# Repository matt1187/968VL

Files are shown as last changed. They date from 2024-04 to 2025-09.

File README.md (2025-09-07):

# Project  MK-968VL 
An (old) project for 486 platform: Video card based S3 Vision 968 VLB with 4MB VRAM.
It is just a Replica of the SPEA Mercury P64V PCI, in which their PCI interface was replaced by a VLB interface.
It is my first project with KiCad, it may sometimes look not so good and weird.

[Full development history at Vogons](https://www.vogons.org/viewtopic.php?f=63&t=76602)

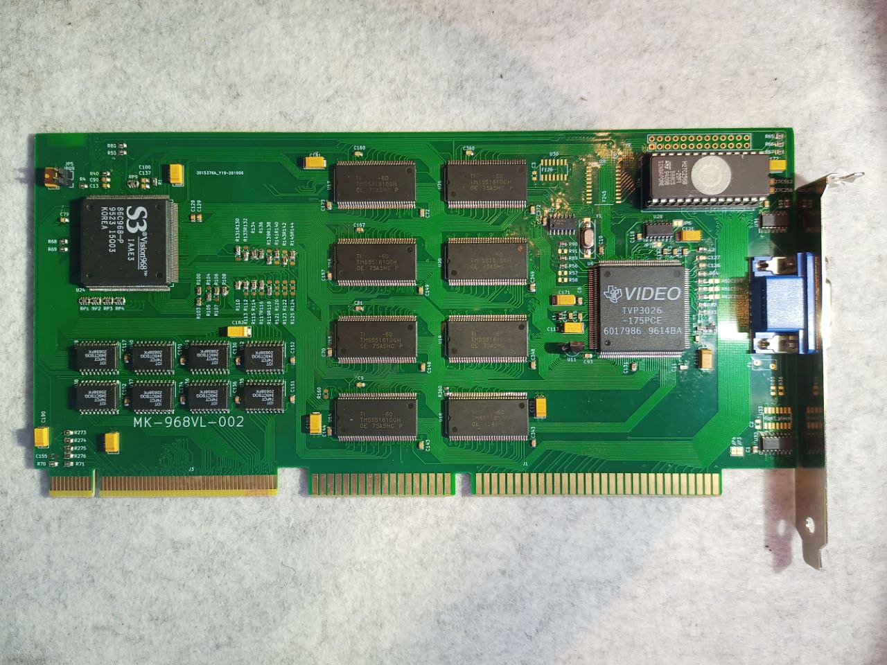
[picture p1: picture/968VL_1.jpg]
pictures


# Features
- S3 Vision968 video chipset, one of fastest Windows accelerator for the 486 VESA local bus platform
- 4 MB VRAM
- 175/220 MHz high quality RAMDAC
- Mostly rock solid 50 MHz bus clock with zero wait states
- Win 3.1 and Win 9x driver available

# Issues
- DDC interface is not working, fixing in future is not planned, sorry.
- heavy to find a S3 Vision968 (86C968) chip
- Card would work with a S3 Vision964 (86C964) too, but that would need modification of VGA-ROM (difference in registers) so that text/CGA/MDA modes work correctly
- Some (many) TVP3026 DAC has issuses with VESA 4bit Mode: Line Jitter  (my original SPEA Mercury P64V PCI has also line jitter) Side notice: I have two 968VL with good 4bit VESA mode

# Bill of Materials
- [**please read file "note_MK_968VL_002.txt"**](https://github.com/matt1187/968VL/blob/main/gerber/note_MK_968VL_002.txt)
- [config resistor picture](https://github.com/matt1187/968VL/blob/main/gerber/config_resistor.JPG)
- [bom csv file Rev 002 ](https://github.com/matt1187/968VL/blob/main/gerber/968.csv)
- [gerber files Rev 002 ](https://github.com/matt1187/968VL/blob/main/gerber/)
- [drawing of slot bracket rev 000-002 ](https://github.com/matt1187/968VL/blob/main/mechanical/bracket_968VL_01.pdf)

# Drivers & ROM
- [ROM dump](https://github.com/matt1187/968VL/blob/main/rom/968V_ROM.zip)
- [Windows 9x driver](https://github.com/matt1187/968VL/blob/main/driver/W95_S3_driver%200109B.ZIP)
- [Windows 3.1 driver](https://github.com/matt1187/968VL/blob/main/driver/WIN31_vision96815B4.ZIP)

# PCB Revision History
- 000 initial draft
- 001 major bug fixing (swapped inner layer, few wrong connections on ICs)
- 002 minor bug fixing (wrong footprint)
- 003 new revision moved VGA port (keystone 9200-1 instead special pc slot bracket) and corrected ISA slot position (12.7mm instead 13 mm  to VLB )

# License
The project is free for non-commercial reproduction. Do not sell it on Ebay or other platforms for profit. Do not make a closed source derivative. Share your experiences and ideas with the community.

This work is licensed under a [Creative Commons Attribution-NonCommercial-ShareAlike 4.0 International License][cc-by-nc-sa].

[][cc-by-nc-sa]

[cc-by-nc-sa]: http://creativecommons.org/licenses/by-nc-sa/4.0/
[cc-by-nc-sa-image]: https://licensebuttons.net/l/by-nc-sa/4.0/88x31.png

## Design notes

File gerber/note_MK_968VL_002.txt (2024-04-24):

Notice for make of   MK_968VL_002 card.

1.) most important: your risk  and  no right by full support.

Component-list:
U33			let U33 empty,  DDC Interface doesn't run right (and failed hardware cursor)
L3 & U11 	place L3 OR  U11, you must not place both at same time. I recommend  place  78L05 for better PLL stability

C155		optional, place it if 968VL is  restarting sometimes.
C103,C104,C105  optional, recommend for improvement of pictures quality.
All 10nF capacitor can be replaced with 100nF capacitor, recommend.   10nF was old design value

count without  units = resistor  (example: 10 = 10 ohm )

Config-Resistor with 47k resistor, pleas see attached pictures "config_resistor.jpg".

PCB-making: jlcpcb can make this pcb. 5 pieces  ~$45

Important: 
4 layers
Impedance JLC7628
PCB thick : 1.6mm
Gold finger: recommend yes with option "45°finger chamfered"
FR-Material: TG130-140C (Standard)
Flying probe test: YES
Copper weight  1oz

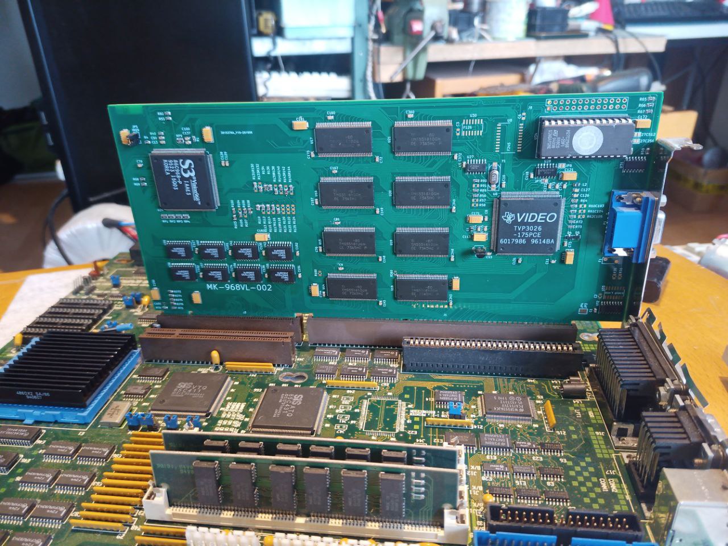
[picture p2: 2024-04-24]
picture/968VL_3.jpg

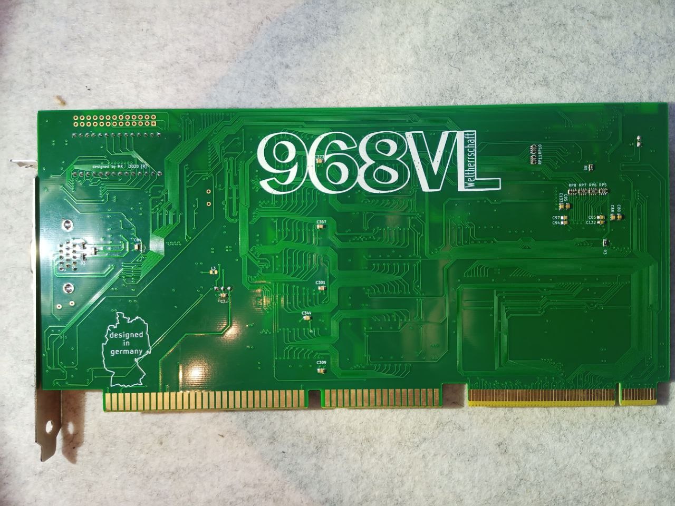
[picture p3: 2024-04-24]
picture/968VL_2.jpg

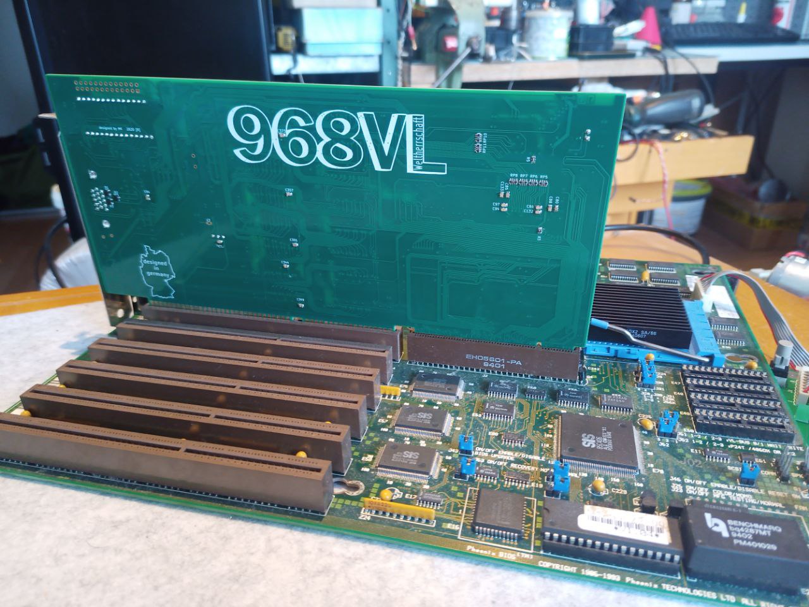
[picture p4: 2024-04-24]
picture/968VL_4.jpg

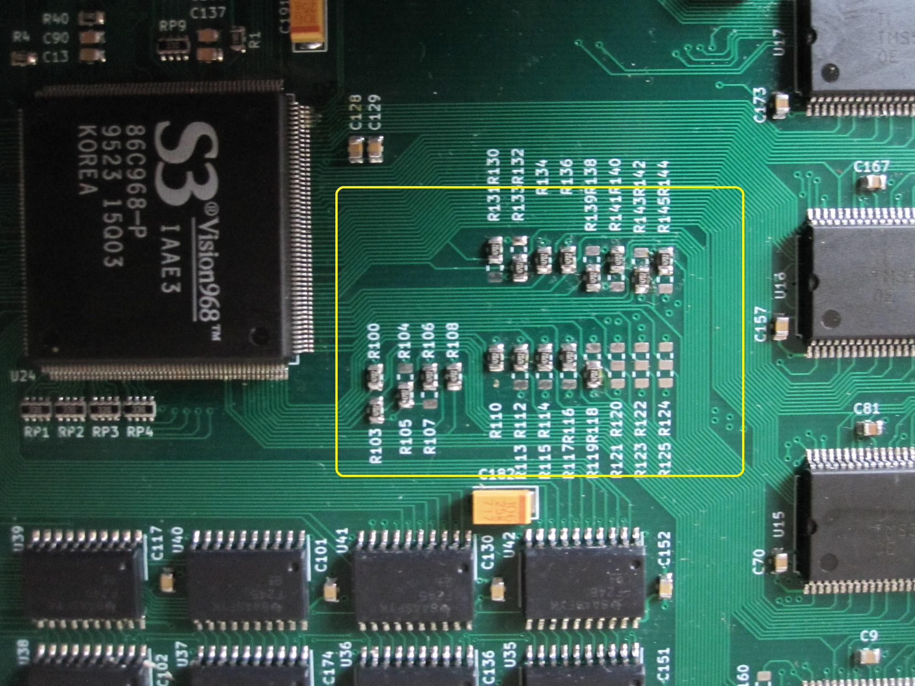
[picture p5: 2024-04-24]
gerber/config_resistor.JPG

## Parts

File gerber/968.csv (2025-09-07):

ID | footprint | case | piece | type | supplier & reference
10 | C103,C104,C105 | 0805 | 3 | 33pf | C0805C330J1GACAUTO
49 | C155 | 0805 | 1 | 330pf | C0805X331M5GACTU
21 | C90,C85,C97,C86,C88,C100,C129,C124,C123,C122,C4,C118,C5,C6,C3,C2,C1,C126,C127, C7,C11,C13,C133,C94,C132,C80,C79,C137,C128,C84,C73,C114,C115,C10,C8,C93,C344,C373,C357,C381,C309,C131,C343,C348,C349,C372,C9,C70,C81,C148,C144,C143,C157,C173,C149,C72,C167,C360,C160,C102,C117,C174,C101,C130,C136,C151,C152 | 0805 | 67 | 100nF | CC0805ZRY5V9BB104
13 | C182,C172,C191,C190,C192,C193,C181,C171,C180,C170,C116,C121 | EIA-6032-28 |  | 10µF 25V Tantal | T491C106M016AT7280
15 | C113 | CP_EIA-6032-28 | 1 | 47µF 10V | TPSC476K010R0200
2 | D5,D4,D3,D2,D1 | SOT-23 | 5 | BAV99 | BAV99,215
3 | F1 | Polyfuse RUEF | 1 | Polyfuse RUEF090 | RUEF090S
26 | R57,R58,R91 | 0805 | 3 | open
1 | R3 | 0805 | 1 | 10 | CR0805AFX-10R0EAS
28 | R1,R5,R70,R72,R73,R56,R89, R40 | 0805 | 8 | 33 | ERJ-6RED33R0V
42 | R60,R61,R62 | 0805 | 3 | 75 | CR0805-JW-750ELF
14 | R88,R71 | 0805 | 2 | 100 | CRCW0805100RFKEAC
15 | R55,R90 | 0805 | 2 | 220 | CRCW0805220RFKEAC
44 | R273,R274,R275,R276 | 0805 | 4 | 330 | CRCW0805330RJNEAC
43 | R360,R160 | 0805 | 2 | 390 | CR0805-JW-391ELF
37 | R64 | 0805 | 1 | 523 or "510" | CR0805-FX-5230ELF
32 | R59 | 0805 | 1 | 820 | CR0805-JW-821EPF
31 | R4,R35,R36,R67,R66,R65,R69,R68 | 0805 | 8 | 10k | CRCW080510K0FKEAC
45 | R143,R141,R145,R139,R138,R140,R144,R142,R131,R133,R132,R136,R130,R134,R113,R124,R125,R122,R123,R120,R121,R118,R119,R116,R117,R114,R115,R110,R112,R108,R106,R107,R105,R104,R103,R100 | 0805 | 36 | 47k | CRCW080547K0FKEAC
24 | RP10,RP11,RP9,RP8,RP7,RP6,RP5,RP4,RP3,RP2,RP1 | R_Array_Convex_4x0603 | 11 | 33 | YC164-JR-0733RL
9 | P1 | DSUB-15-HD_Female_Horizontal_P2.29x1.98mm_EdgePinOffset8.35mm_Housed_MountingHolesOffset10.89mm_wide | 1 | DSUB-15 HD 90° 8.89mm | L77HDE15SD1CH4R or L77HDE15SD1CH4RHNVGA
34 | J9 | PinHeader_2x13_P2.54mm_Vertical | 1 | 2x13 2.54mm pin header
17 | JP5 | PinHeader_1x02_P2.54mm_Vertical | 1 | IRQ9 | 2x1 2.54mm pin header
7 | Y1 | Crystal_SMD_HC49-SD | 1 | 14,31818 MHz | FOXSDLF/143R-20/TR
12 | L3,L2,L1 | 0805 | 3 | 10uh | MLZ2012N100LTD25
18 | U14,U15,U16,U18,U19,U20,U21,U17 | SO-64(VRAM)_SMALL | 8 | TMS55160 OR "TMS55161" OR "KM4216C258" OR "IBM025160" OR "IBM025161" | TMS55160 or TMS55161 or "KM4216C258" or "IBM025160" or "IBM025161"
22 | U11 | TO-92 | 1 | 78L05
30 | U6 | PQFP-160_28x28mm_P0.65mm | 1 | TVP3026-175 or 220
33 | U28 | SOIC-14 | 1 | 74F74 | SN74F74DR
35 | U8,U57,U39,U41,U42,U40,U38,U37,U36,U35 | SO-20 | 10 | 74F245 | SN74F245DWR
52 | U24 | PQFP-208_28x28mm_P0.5mm | 1 | S3 Vision968(TM) | 86C968-P
38 | U27 | SOIC-14 | 1 | 74F14 | SN74F14DR
41 | U30 | SOIC-14 | 1 | 74F126 | SN74F126DR
39 | U31 | SOIC-14 | 1 | 74F125 | SN74F125DR
11 | U32 | SOIC-16;1;74F174" | SN74F174ADRE4
40 | U33 | SOIC-14 | 1 | 74LS125 | don't place
36 | U34 | DIP-28_15.24 | 1 | 27C512 or "27C256" and "28pole DIP socket width 15.24mm" | o: DILB28P-223TLF

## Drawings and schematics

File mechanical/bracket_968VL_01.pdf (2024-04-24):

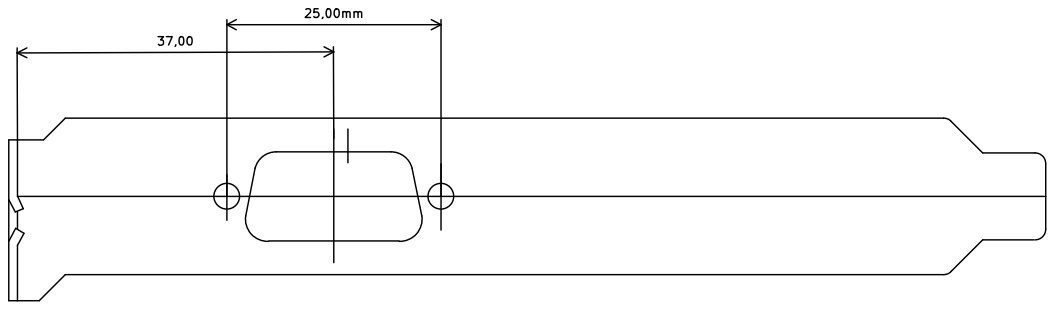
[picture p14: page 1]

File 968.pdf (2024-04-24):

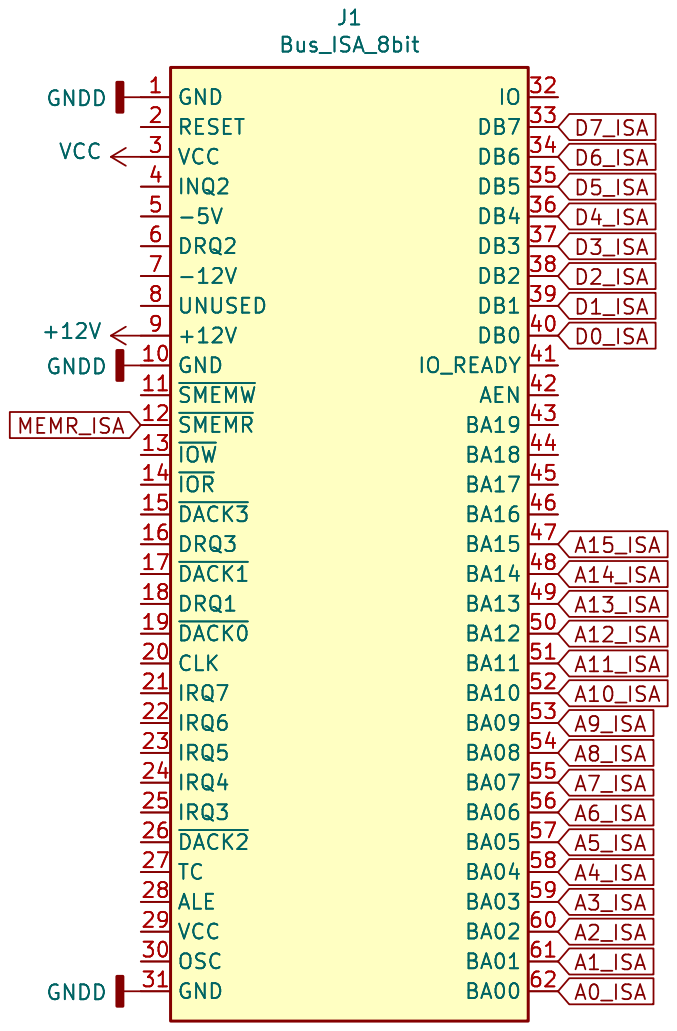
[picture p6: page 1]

Id: 1/8 Title: File: 968.sch Sheet: /

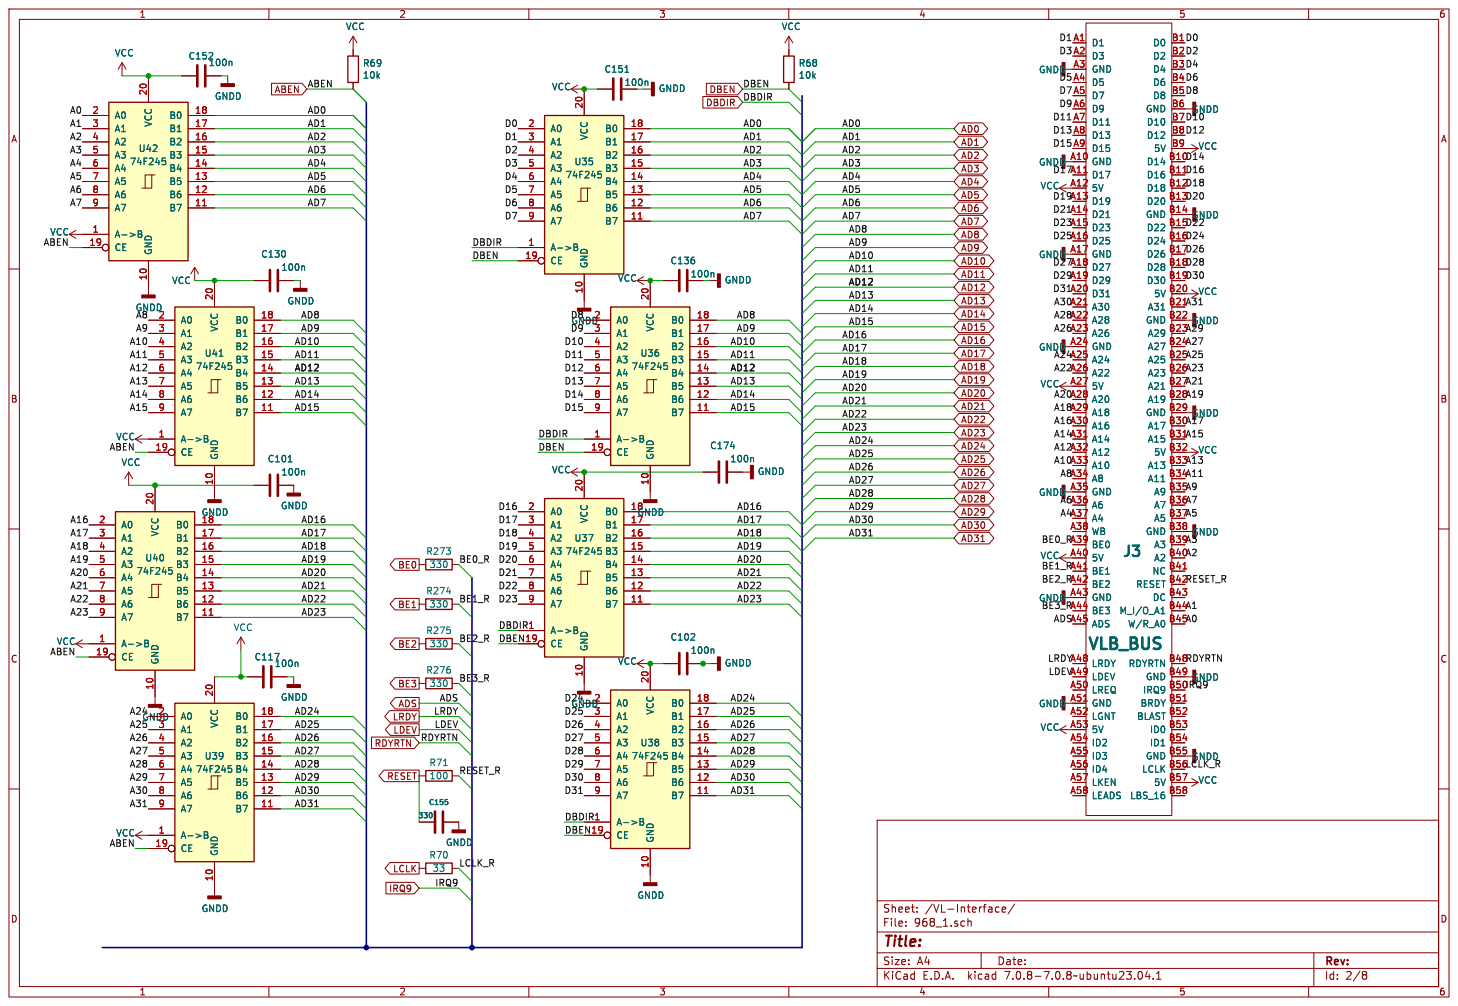
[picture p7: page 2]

10k VCC
D1 A1 GND A10 D17 A11
5V A12 D19 A13 D21 A14 D23 A15 D25 A16 GND A17 D27 A18 D29 A19 D3 A2 D31 A20 A30 A21 A28 A22 A26 A23 GND A24 A24 A25 A22 A26
5V A27 A20 A28 A18 A29 GND A3 A16 A30 A14 A31 A12 A32 A10 A33 A8 A34 GND A35 A6 A36 A4 A37 WB A38 BE0 A39 D5 A4
GNDD
5V B32 A13 B33 A11 B34 A9 B35 A7 B36 A5 B37 GND B38 A3 B39 D6 B4 A2 B40 NC B41 RESET B42 DC B43 M_I/O_A1 B44 W/R_A0 B45 RDYRTN B48 GND B49

5V B20 A31 B21 GND B22 A29 B23 A27 B24 A25 B25 A23 B26 A21 B27 A19 B28 GND B29 D4 B3 A17 B30 A15 B31

VCC GNDD GNDD GNDD

Id: 2/8 Title: File: 968_1.sch Sheet: /VL-Interface/ R273

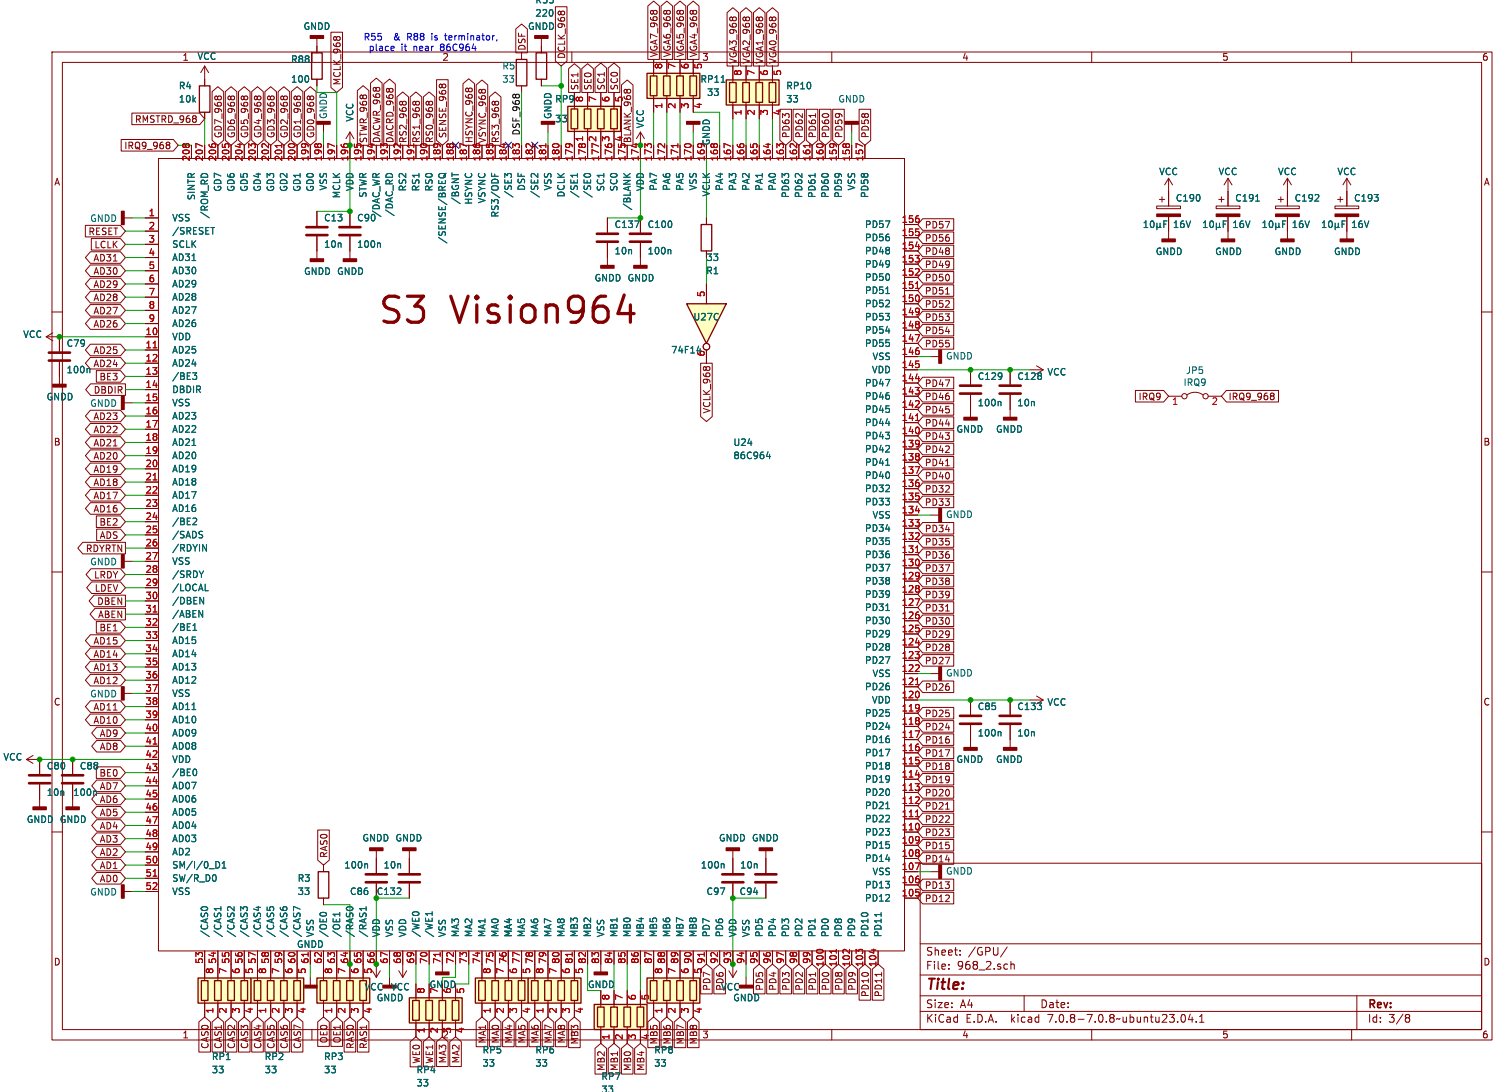
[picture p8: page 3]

Id: 3/8 Title: File: 968_2.sch Sheet: /GPU/

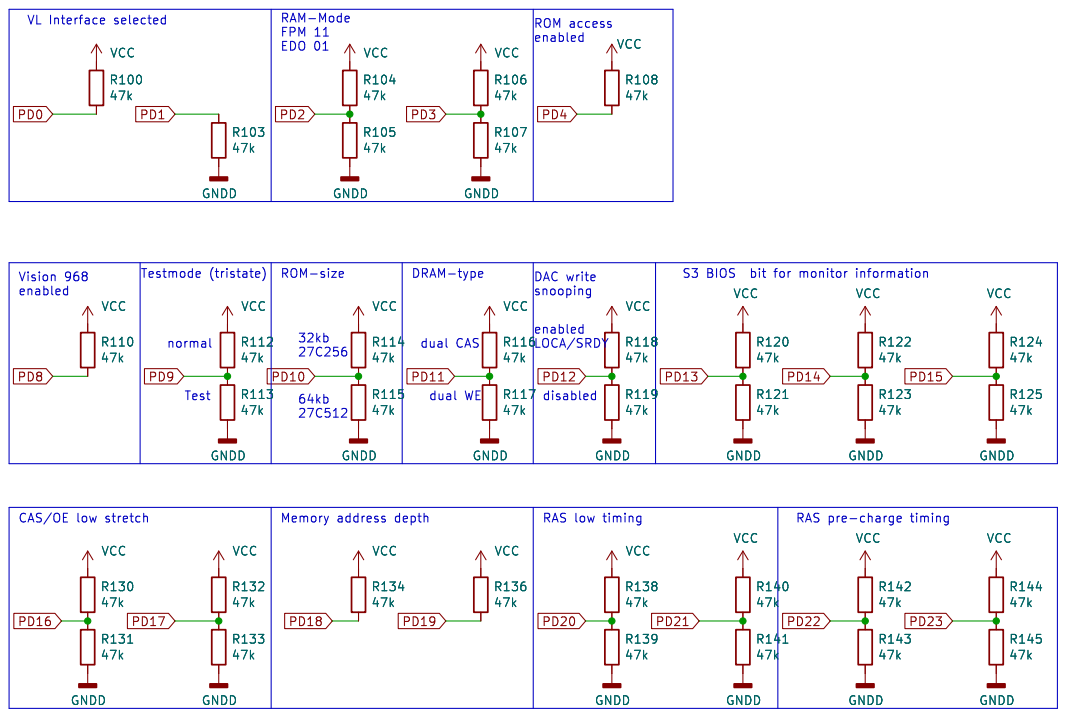
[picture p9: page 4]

Id: 4/8 Title: File: 968_6.sch Sheet: /PD_Strap_Resistor/

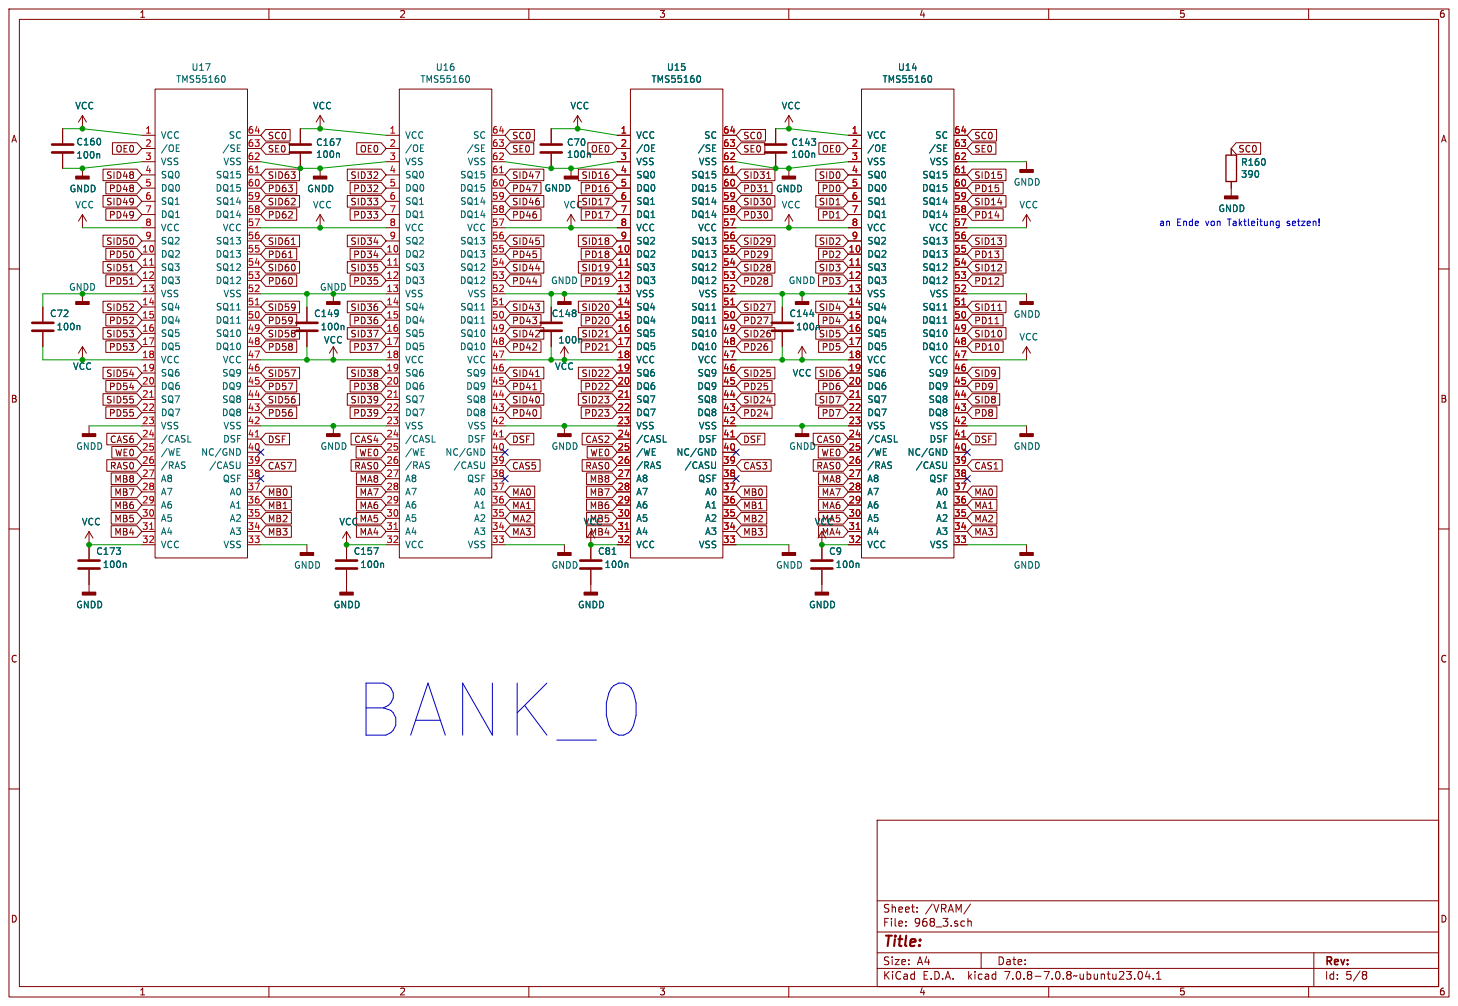
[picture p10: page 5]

Id: 5/8 Title: File: 968_3.sch Sheet: /VRAM/ VCC

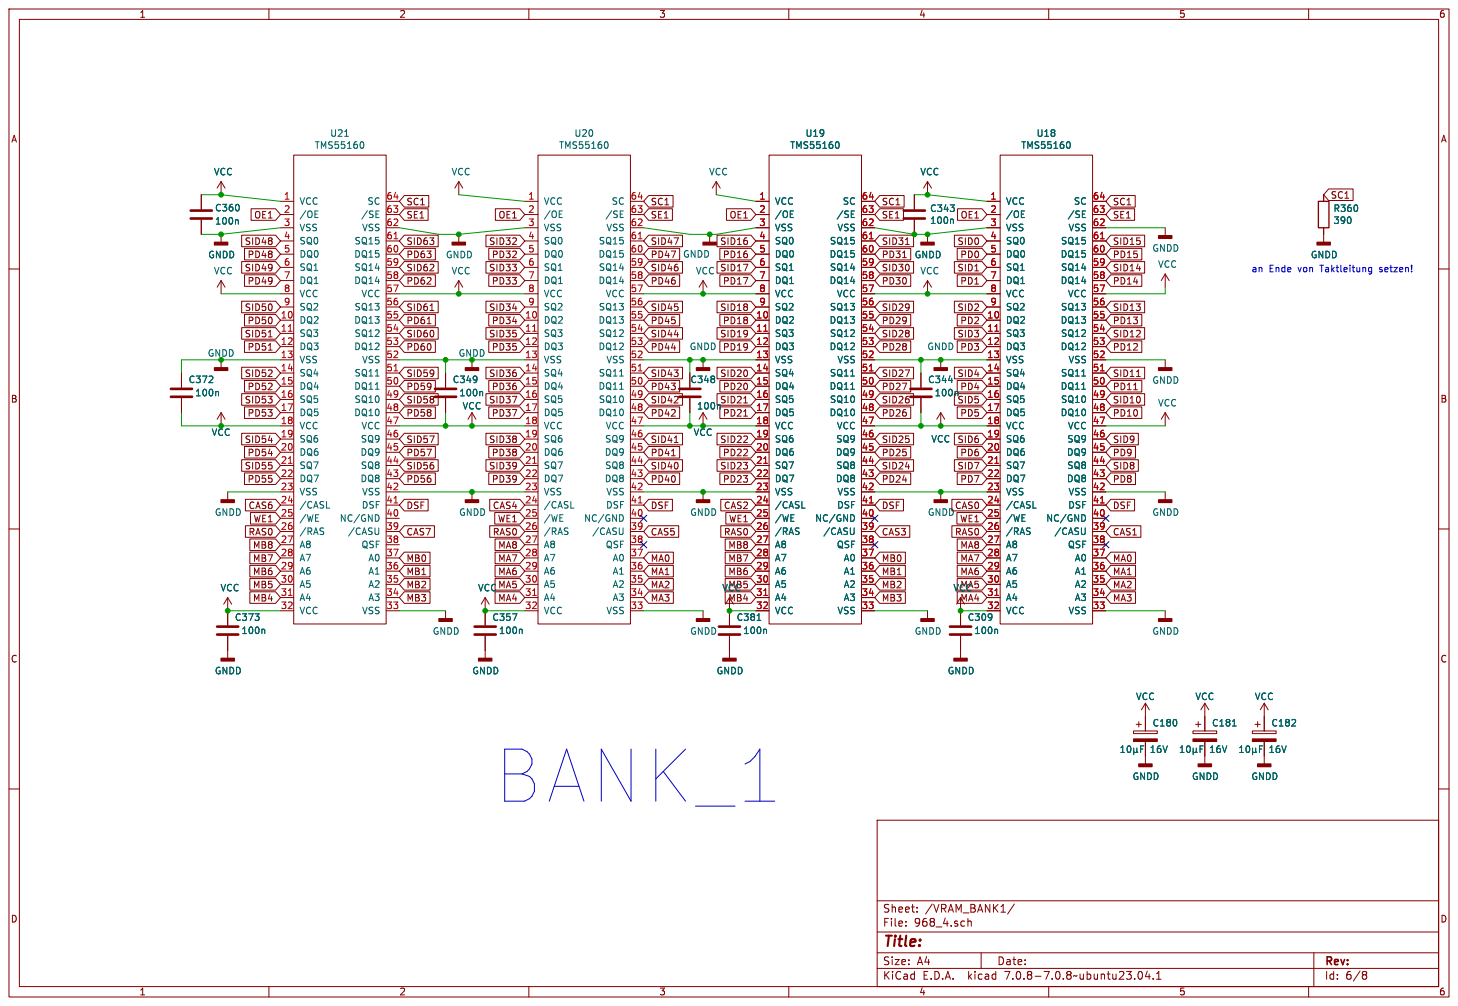
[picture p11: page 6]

Id: 6/8 Title: File: 968_4.sch Sheet: /VRAM_BANK1/ VCC

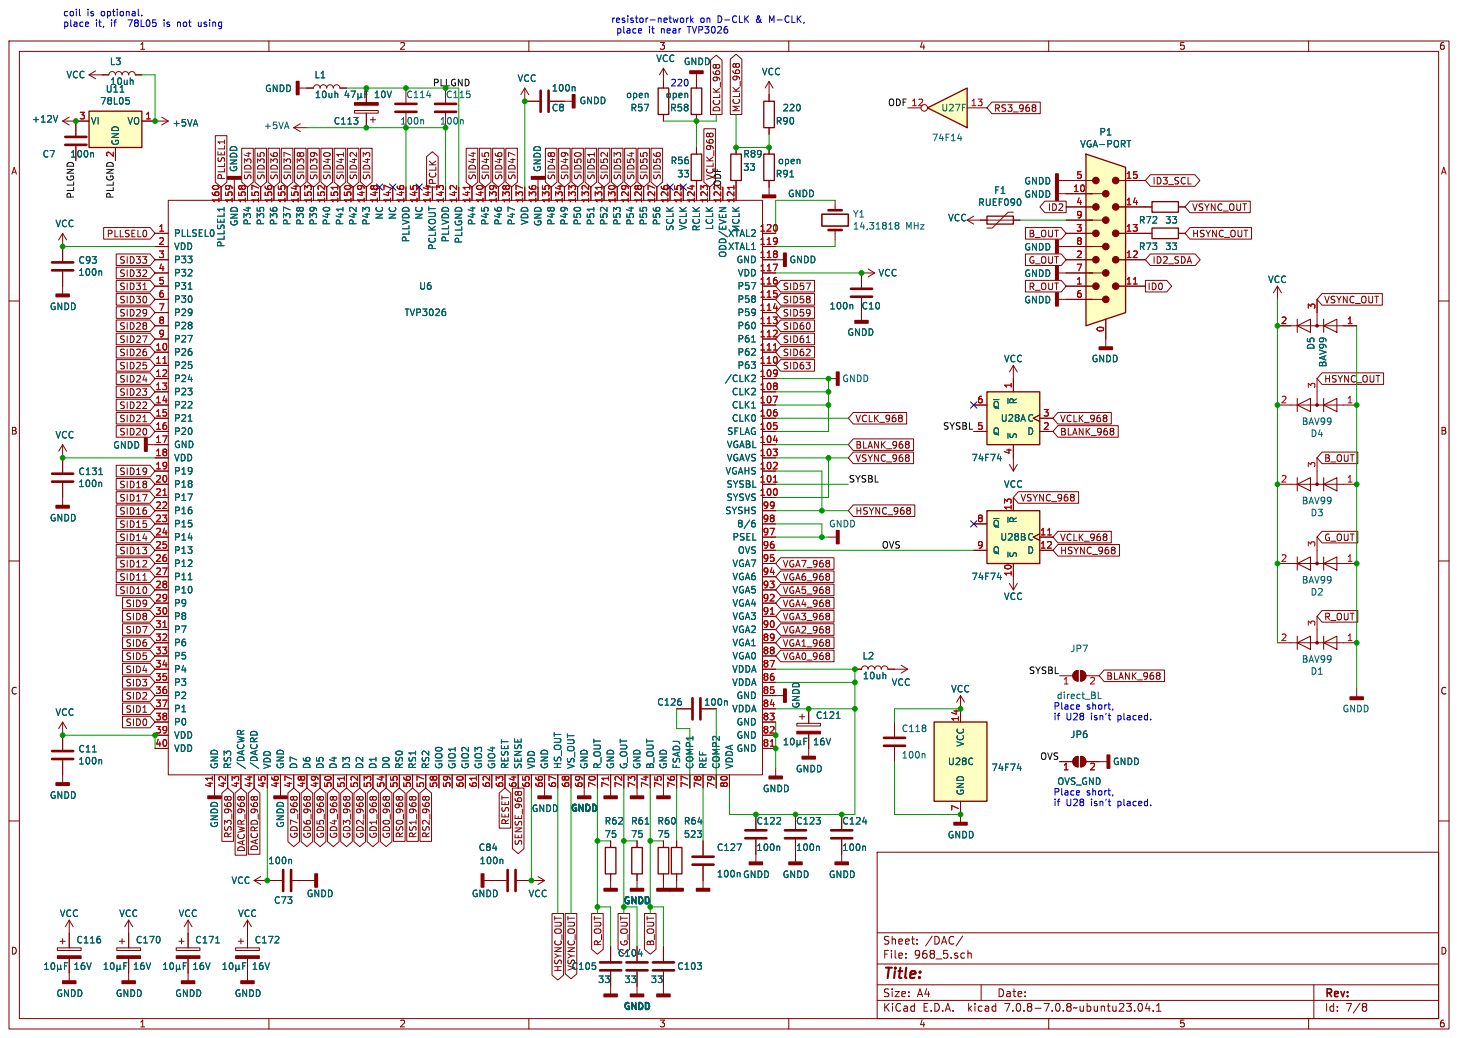
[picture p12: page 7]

if U28 isn't placed. Place short,
JP6 OVS_GND

33 GNDD
Id: 7/8 Title: File: 968_5.sch Sheet: /DAC/ GNDD GNDD

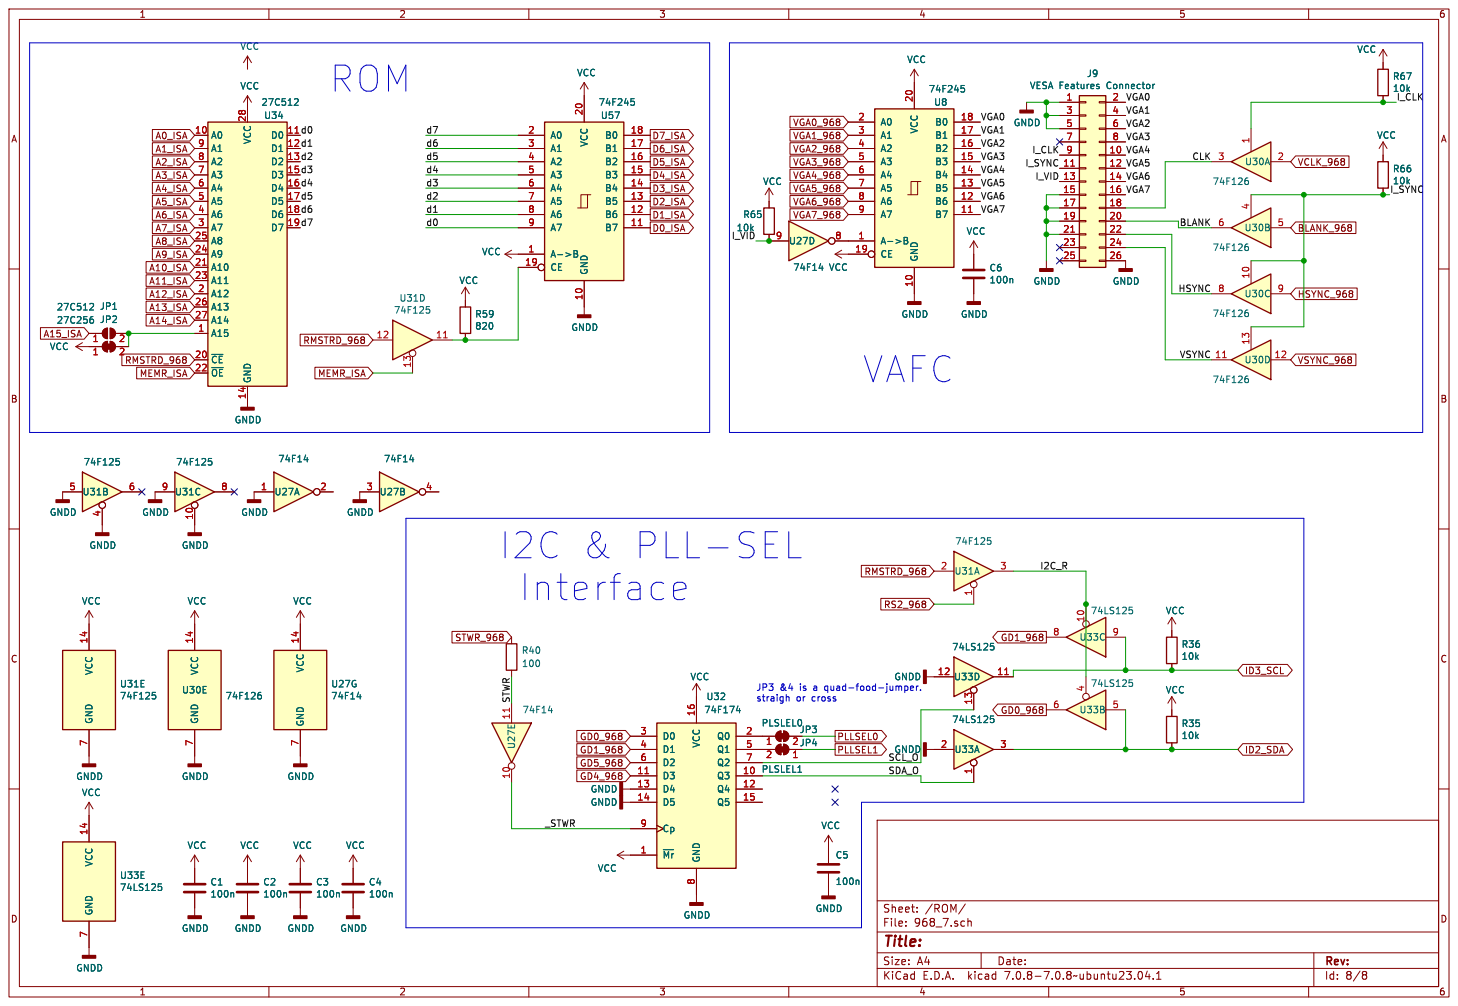
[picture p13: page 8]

J9 VESA Features Connector GNDD

JP3 &4 is a quad-food-jumper.

VCC GNDD VCC 14 GND

Id: 8/8 Title: File: 968_7.sch Sheet: /ROM/
